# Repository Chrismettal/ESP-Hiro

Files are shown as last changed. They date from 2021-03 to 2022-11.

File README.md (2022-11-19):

# ESP-Hiro 広 <!-- omit in toc -->

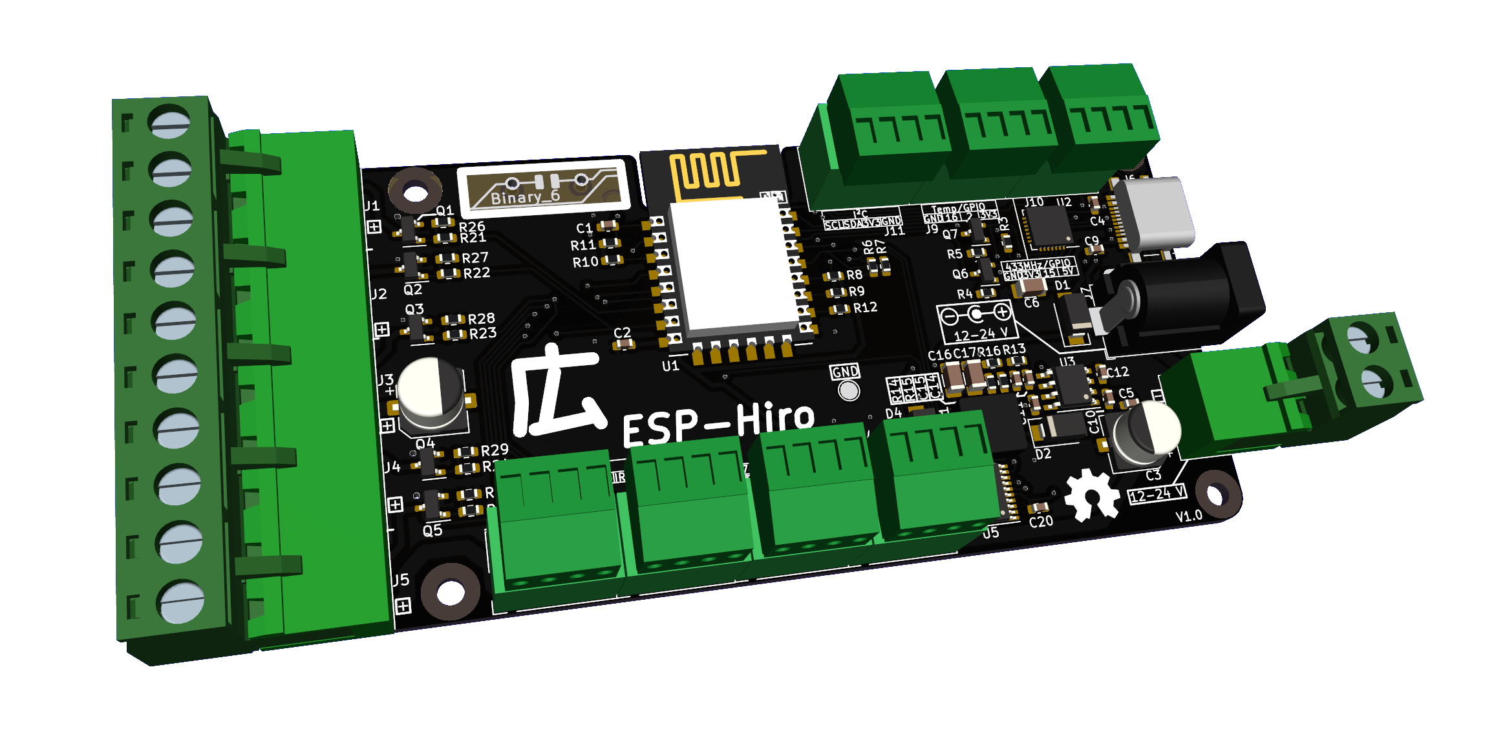
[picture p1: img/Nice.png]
Board


## Interested in buying?

You can find the mostly assembled kit as well as 3D printed parts over at my tindie store!



**If you like my work please consider [supporting my caffeine addiction](https://gitlab.com/Chrismettal#donations)!**

# Contents

- [Contents](#contents)
- [What is this?](#what-is-this)
- [Pin tables](#pin-tables)
  - [Devices](#devices)
- [Defined I/O](#defined-io)
  - [MOSFETs](#mosfets)
  - [IR](#ir)
  - [Relays](#relays)
  - [I²C](#ic)
    - [PCF8574](#pcf8574)
    - [Temperature Sensors](#temperature-sensors)
    - [433MHz](#433mhz)
    - [ADC](#adc)
    - [Other](#other)
- [Software](#software)
  - [Tasmota](#tasmota)
  - [Other](#other-1)
- [Build / aquire / use](#build--aquire--use)
  - [Buying](#buying)
  - [Building my own](#building-my-own)
  - [3D printing](#3d-printing)
  - [Mechanical](#mechanical)
  - [Power supply](#power-supply)
  - [Jumpers](#jumpers)
    - [V-USB -\> +5V](#v-usb---5v)
    - [PCF8574](#pcf8574-1)
    - [IR resistor](#ir-resistor)
    - [Deep sleep](#deep-sleep)
  - [Uploading the Firmware](#uploading-the-firmware)
  - [Templates](#templates)
- [Tools used](#tools-used)
- [Other boards](#other-boards)
  - [CP2102 USB - serial converter](#cp2102-usb---serial-converter)
  - [24 - 5 V step down converter](#24---5-v-step-down-converter)
- [Changelog](#changelog)

# What is this?

This is a Tasmota compatible dimmer/actuator/sensor and general purpose smart home interface board to either make various devices smart or create new ones. Typical uses include RGBW dimming, single/multi room heating control, even automating plants!

ESP-Hiro has multiple interfaces directly on board which allow you to connect almost anything you would want to have automated. Some parts like a DHT22 or an IR blaster are basically pre-wired on board, all of the ESP8266's usable GPIO are broken out to plugs/sockets, and since the board was (and still is) pretty empty I've thrown in a PCF8574 port expander in case you might think of a usecase with more pins than the ESP has. 

My house is already "smarted-up" with an old version of this, but as I am replacing the old version with this one I will update this repo with the templates of my nodes and pictures of the usecases.

# Pin tables

## Devices

This table shows the hardware that is enabled on the PCB right away. Obviously other hardware can be connected using the I/O headers as you please. `PD` pins are pulled down, `PU` are pulled up.

| | `GPIO2` (PU) | GPIO4 (PU) | GPIO5 (PU) |  GPIO12 (PD) | GPIO13 (PD) | GPIO14 (PD) | `GPIO15` (PD) | `GPIO16` (PD) | `ADC` |
| --- | :---: | :---: | :---: | :---: | :---: | :---: | :---: | :---: | :---: |
| Header for I/O | Temp | SDA | SCL | 12 | 13 | 14 | 15 | 16 (HIGH AT BOOT)  |  ADC  |
| I²C | | SDA | SCL | | | | | | |
| Deep Sleep | | | | | | | Disable | RST | |
| ADC | | | | | | | | | X |
| 433Mhz Transmitter | | | | | | | X | | |
| AM2302/DHT22 | X | | | | | | | | |
| DS18x20 | X | | | | | | | | |
| 2.5 A MOSFET PWM | | | | Ch1 | Ch2 | Ch3 | Ch4 | Ch5 (HIGH AT BOOT) | |
| IR Transmitter | | | | | | | | IR | |
| PCF8574 | | SDA | SCL | `INT (jumper)` | | | | | |

| | `GPIO2` | GPIO4 | GPIO5 | GPIO12 | GPIO13 | GPIO14 | `GPIO15` |  `GPIO16` | `ADC` |
| --- | :-----: | :---: | :---: | :---: | :---: | :---: | :---: | :---: | :---: |
| Room Controller |  DHT22  | | | PWM R | PWM G | PWM B | PWM W | PWM Heating | |
| Switching Actuator | Button  | | | Q1 | Q2 | Q3 | Q4 | Q5 | |
| IR AC Controller | DS18S20 | | | Button 1 | Button 2 | | | IR | |
| Automated Plant |  DHT22  | SDA LCD + Light sensor | SCL LCD + Light sensor | FET water pump | FET fertilizer pump | PWM light | SR04 Trigger |  SR04 Echo  | Soil Moisture |
| Info Display | | SDA LCD | SCL LCD | Encoder A | Encoder B | Encoder Button | | | |

# Defined I/O

## MOSFETs

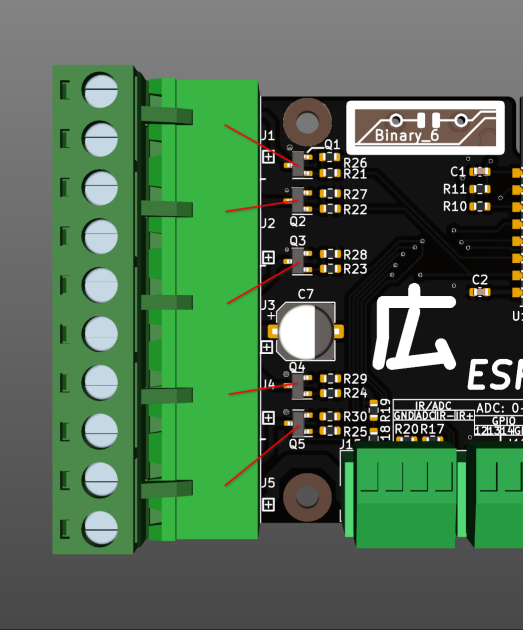
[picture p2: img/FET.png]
FET


On board MOSFETs can be used to switch or PWM dim loads up to 75 W. Uses include RGB-WW-CW LEDs, heating actuators, small motors/pumps etc. The board can supply 5 A overall, every FET individually can provide up to 2.5 A. Q5 WILL be high at boot, so LEDs connected to this FET will blink once during initial powerup of the board!

- Used FET = AO3400A
- Imax per FET = 2.5 A
- Imax over all FETs = 5 A 
- U = 12 - 24 V

## IR

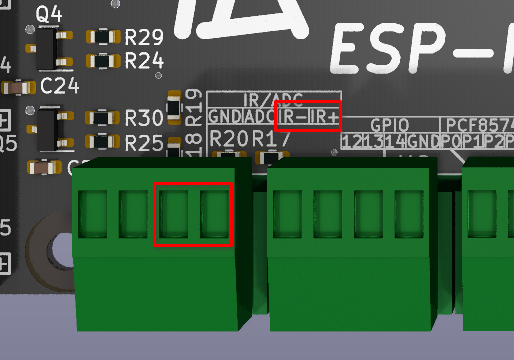
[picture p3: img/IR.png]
IRJack


A header for an IR blaster is present, connected via the MOSFET Q5. It is supplied by 5 V via a jumper configurable current limit resistor of `180 Ohms / 33 Ohms` which works out to around `20 mA / 100 mA` depending on your diodes forward voltage.

`!WATCH OUT!` if you attempt to use an IR LED on J15 and a 24 V device on J5 at the same time you will find that you are connecting the 24 V rail to the 5 V rail through your devices and you will NOT have a fun day! Use ONLY an IR blaster OR a 24 V device at J5!

## Relays

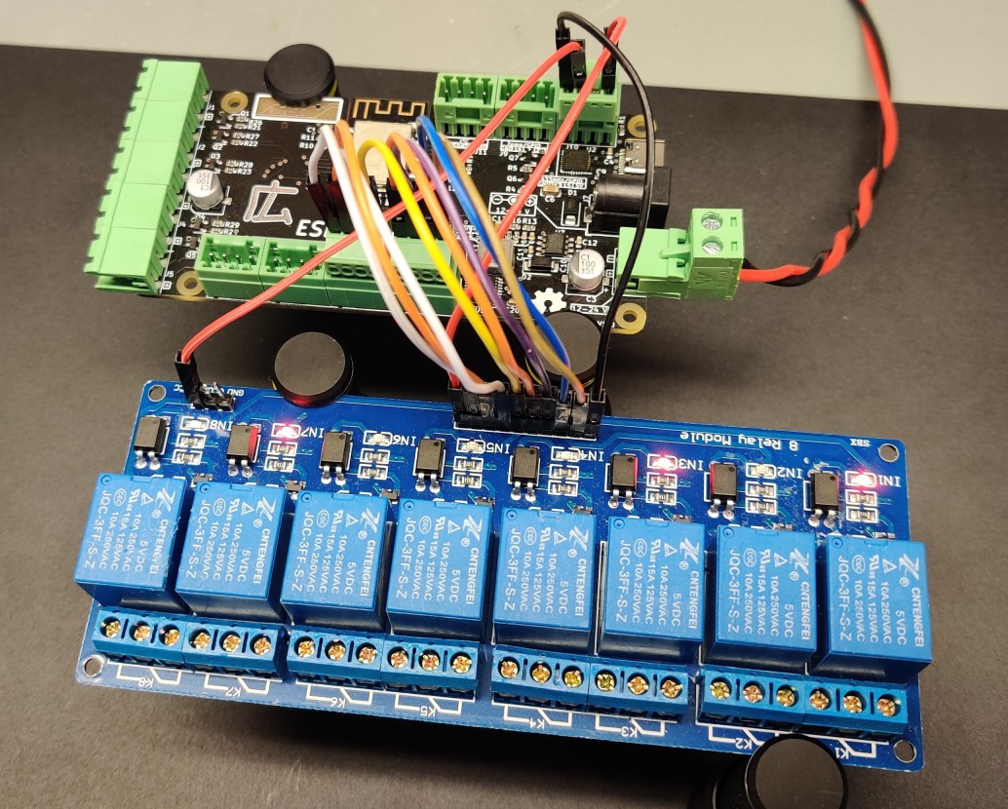
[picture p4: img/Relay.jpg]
RelayBoard


These relay boards can be connected to basically any GPIO from the pin table you want, but you need to disconnect "JD-VCC" jumper and supply 3.3 V to JD so you don't feed 5 V back into the ESP. They can also be connected to the PCF8574 expander header outputs if configured accordingly.

## I²C

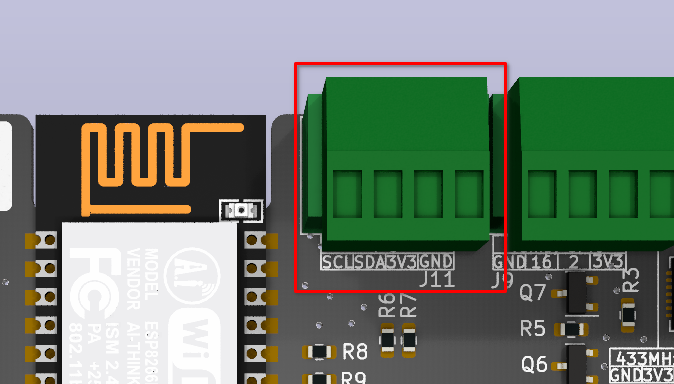
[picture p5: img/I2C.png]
I2C


- `SDA = GPIO4`
- `SCL = GPIO5`

Any I²C devices supported by Tasmota will work, but remember that some devices already include pullup resistors that need to be removed. For example HD44780 LCDs with PCF8574 I²C backpacks will pull up the I²C lines to 5 V, which could damage the ESP and is not needed since I²C is already pulled up to 3.3 V on ESP-Hiro.

For all I²C devices you will have to enable the I²C driver once per command line with `I2Cdriver22 1`

### PCF8574

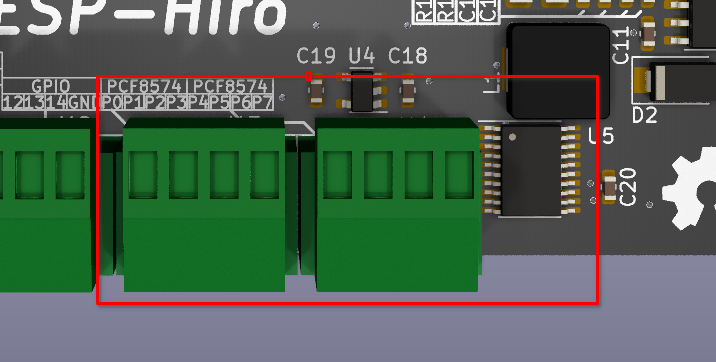
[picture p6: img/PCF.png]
PCF


Tasmota supports Inputs and Outputs over PCF8574 expanders, but to interrupt on input changes GPIO12 needs to be connected to the expander interrupt pin with JP8. Beware that this needs to apply a pullup to GPIO12 with will turn Q1 on! The address of the PCF8574 has to be set with 3 jumpers as well. JP6 enables the PCF at all. 

Setting the following jumpers will enable the PCF including the interrupt pin, and set the PCF address to `0x39` which will be found by Tasmota:

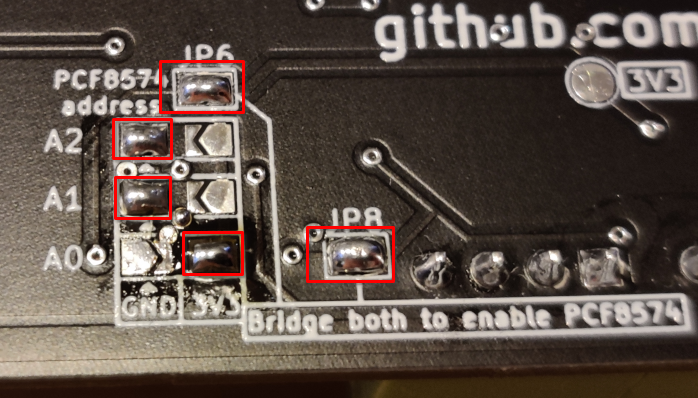
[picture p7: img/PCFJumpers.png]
PCFJumper


### Temperature Sensors

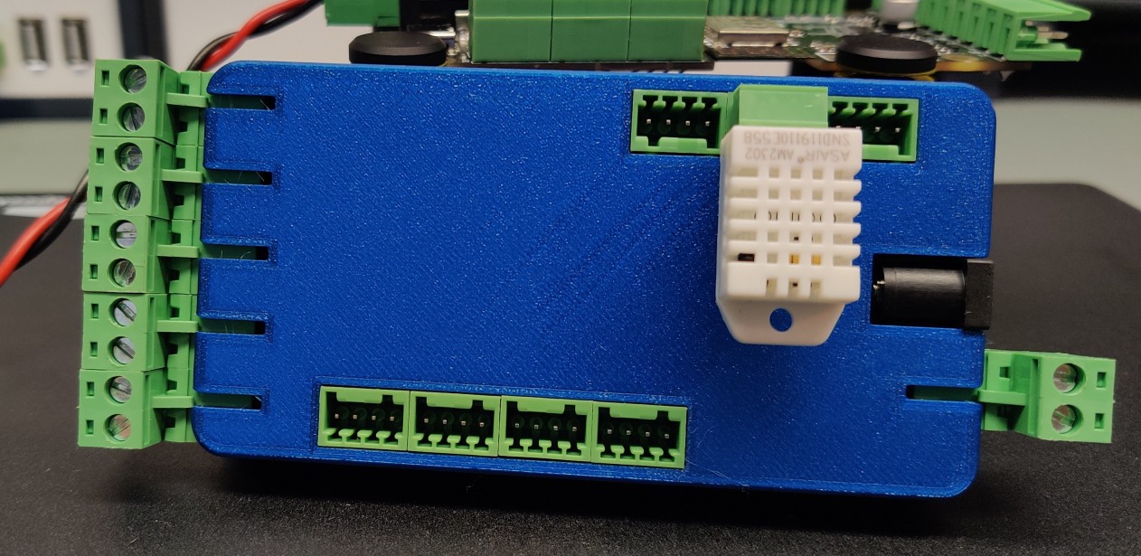
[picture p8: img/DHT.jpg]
Temp


While you can use any temperature sensor supported by Tasmota, the two predefined variants are DHT22 and DS18B20 type sensors. Both are defined to go on `J9` and use `GPIO02`.

### 433MHz

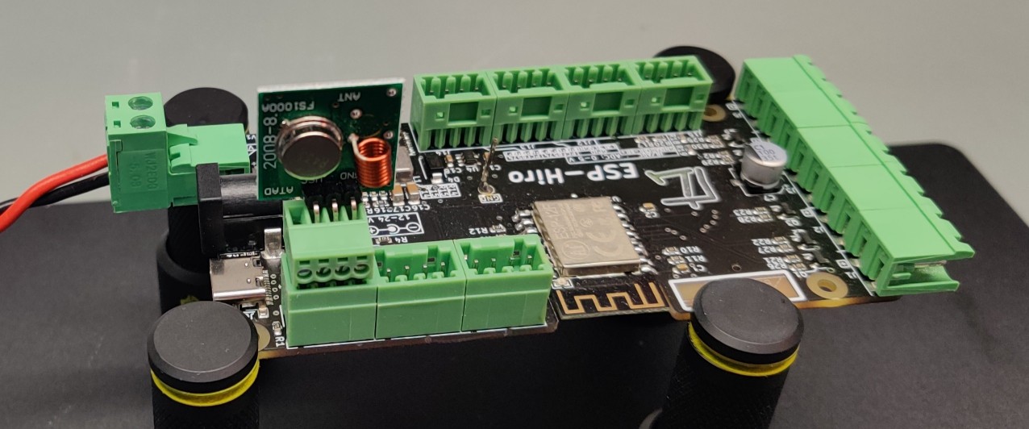
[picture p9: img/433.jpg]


A 433MHz antenna can be plugged straight onto J10, using pin 2-4, which will use GPIO15 for the RC-Switch library.

### ADC

The ADC has a voltage divider in place to measure 0 - 5 V over the 0 - 1023 ADC range

### Other

Tasmota does way more than I anticipated so you can use everything that Tasmota provides, even if not specifically defined here. This just happens to be the stuff I regularly use.

# Software

## Tasmota

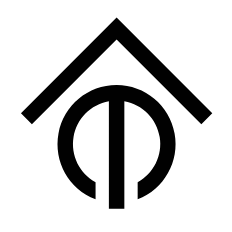
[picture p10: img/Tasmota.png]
Tasmota


Under `/Tasmota/tasmota-ESP-Hiro/` you will find a precompiled `firmware.bin` built for use with ESP-Hiro, as well as a user_config_override.h file so that you can edit your build to your preferences or usecase.
Using the override file requires you to clone the Tasmota repo and placing the override file inside the `/tasmota/` folder there. 

## Other

Obviously as this is basically another ESP8266 devboard you can code your own software in any language you want. The original design of ESP-Hiro was programmed with Arduino but that made it very "hardcoded to my own home" and not flexible enough for publishing. Tasmota is what sparked the idea of a publishable refresh so just use that!

# Build / aquire / use

## Buying

You can find the mostly assembled kit as well as 3D printed parts over at my tindie store!



## Building my own

As this project is fully open sourced you can obviously make your own boards. The whole board is made to be manufactured by JLCPCB and uses their LCSC parts libraries in the BOM. Using the manufacturing files inside the `KiCAD` folder you can have them build the populated PCB for you, but obviously you can just do them by hand if you want! Obviously SMD soldering skills will be required especially for the USB-C terminal, and parts like the CP2102 are best done with a hot air gun, but these two parts aren't even required if you don't plan to upload code via USB.

Right now there is no build guide for soldering one yourself since this was an exercise in design for manufacturing, specifically to get a fully working module delivered from the PCBA house. 

## 3D printing

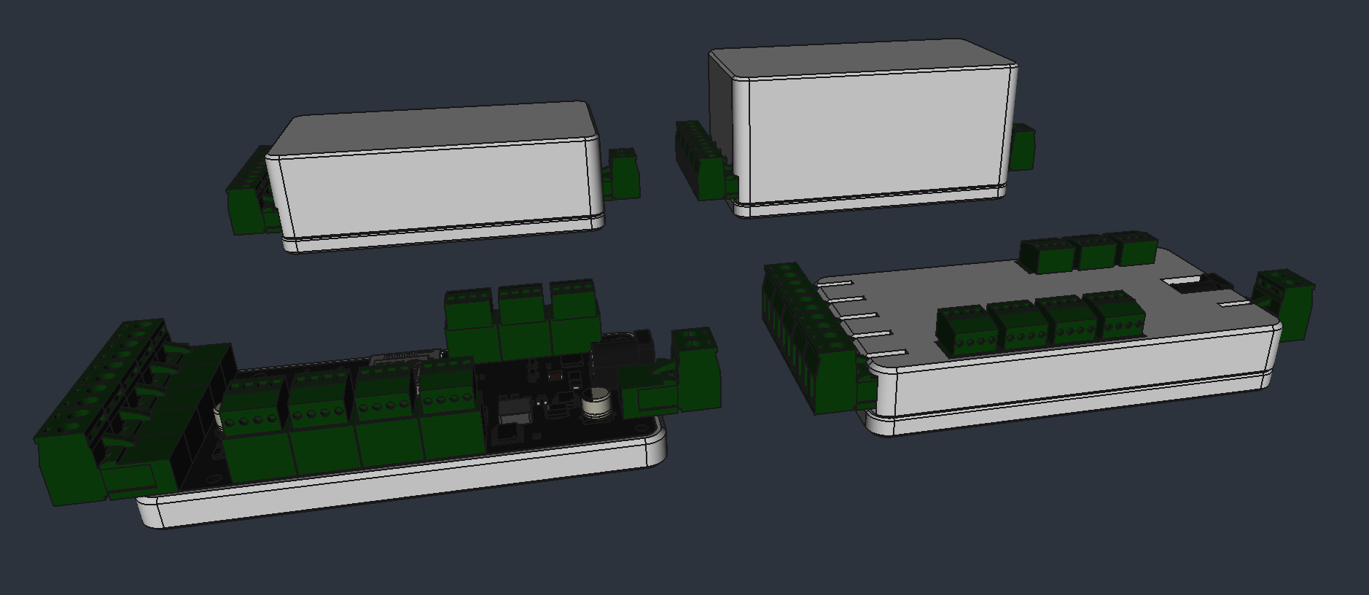
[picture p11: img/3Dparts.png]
3DParts


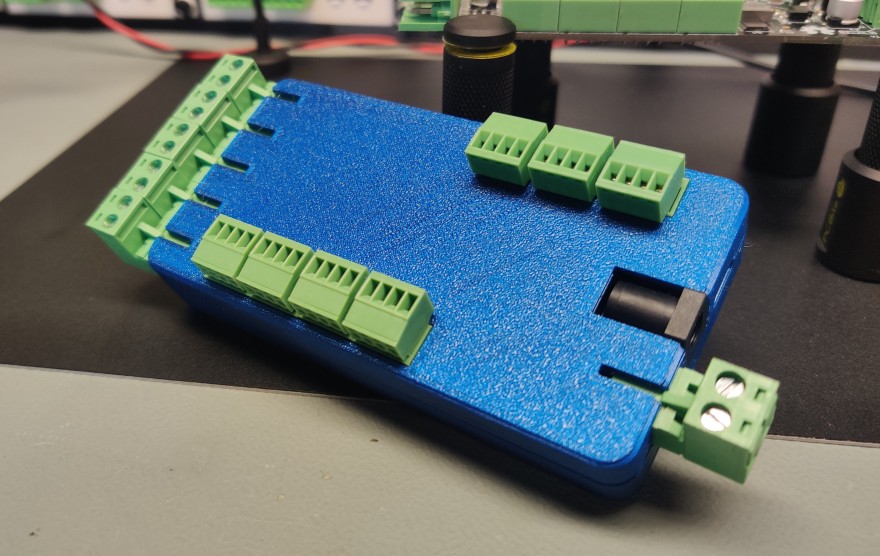
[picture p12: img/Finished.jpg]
Finished


The FreeCAD project file (done in 0.20 dev versions) contains parametric design files for 4 different cases. There is one "Shoe" that only covers the bottom of the PCB, one "Slim" case exposing all connectors, and two "Thicc" cases, only exposing the side connectors. For these variants, printable stl files are exported in the FreeCAD/stl folder.

All cuts and breakthroughs are done in the last steps of each body, so should choose to only populate one of the PWM jacks you can delete the "pocket" operations for the other PWM jacks. The same applies to the screwholes in the bottom as well as most other jacks.

You can also find the project on [PrusaPrinters](https://www.prusaprinters.org/prints/66847-esp-hiro-cases-smart-home-devboard-tasmota-compati)!

## Mechanical

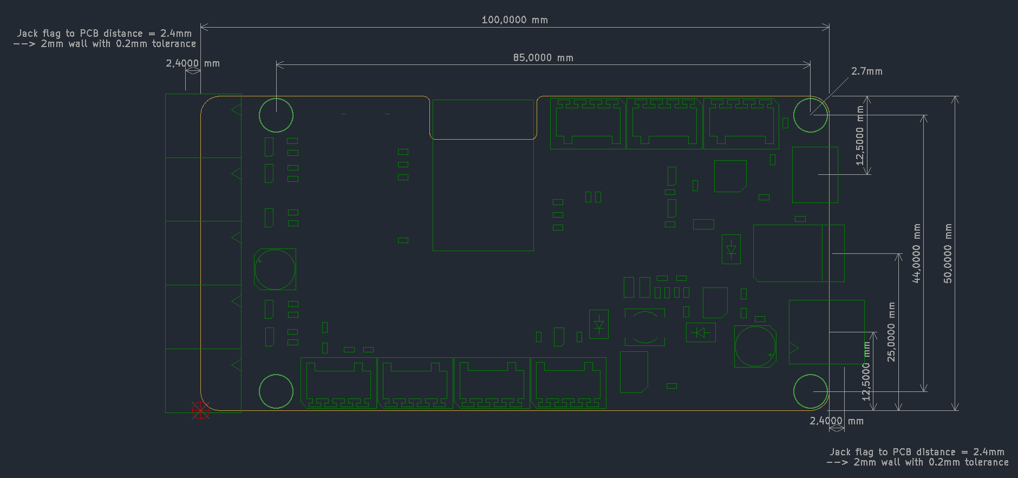
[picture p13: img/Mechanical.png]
Mechanical


This is the mechanical drawing. Under the KiCAD folder /renders you will also find the STEP file for the whole board which makes it easier to design your case around it.
The screwholes are 2.75mm for 2.5mm screws to pass.
Walls around board should be 2mm thick, with 0.2mm space between the board and the wall for the 5.08mm plugs to fit nicely.

## Power supply

The PCB can be easily supplied via 5 V or 12-24 V depending on your usecase. Only the MOSFETs are exclusively supplied through the 12-24 V DC input, everything else will work on 5 V as well.

To supply the unit via 5 V you can use either the USB Jack or via J10:

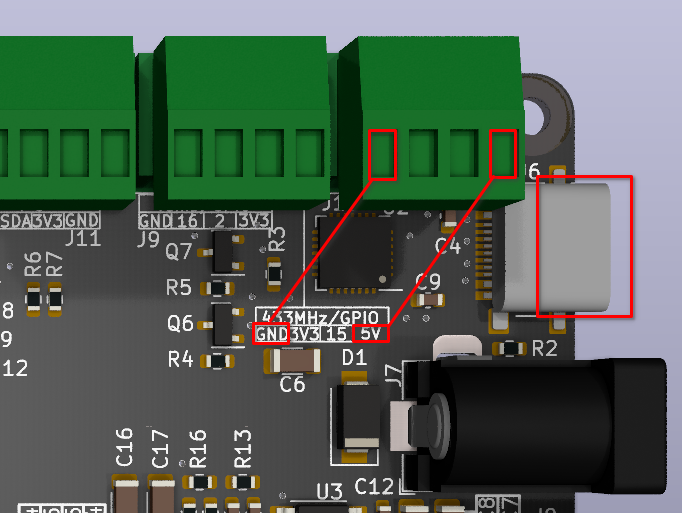
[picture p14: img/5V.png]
5V


12-24 V are supplied via either the barrel jack J7 or the screw-plug terminal J8:

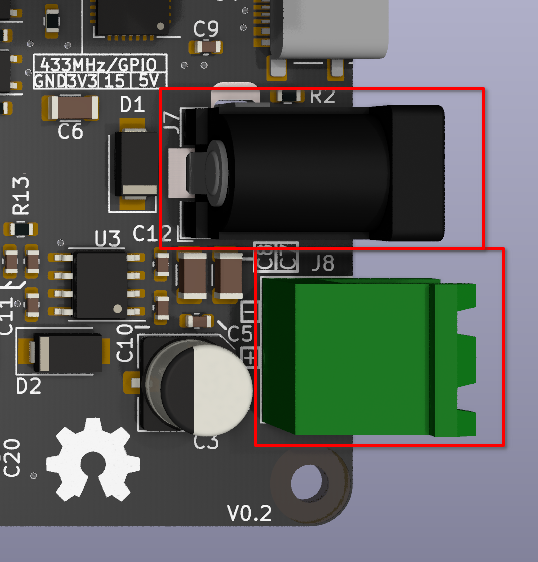
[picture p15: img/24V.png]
24V


The designed current for this board is a maximum of 5 A through the 24 V terminal, which provides you up to 120 W of dimming power, which is plenty for most at-home LED dimming uses. At least for me. 

Using the 3V3 header also works to supply the ESP, but the IR LED for example won't work anymore as it is supplied by 5 V.

## Jumpers

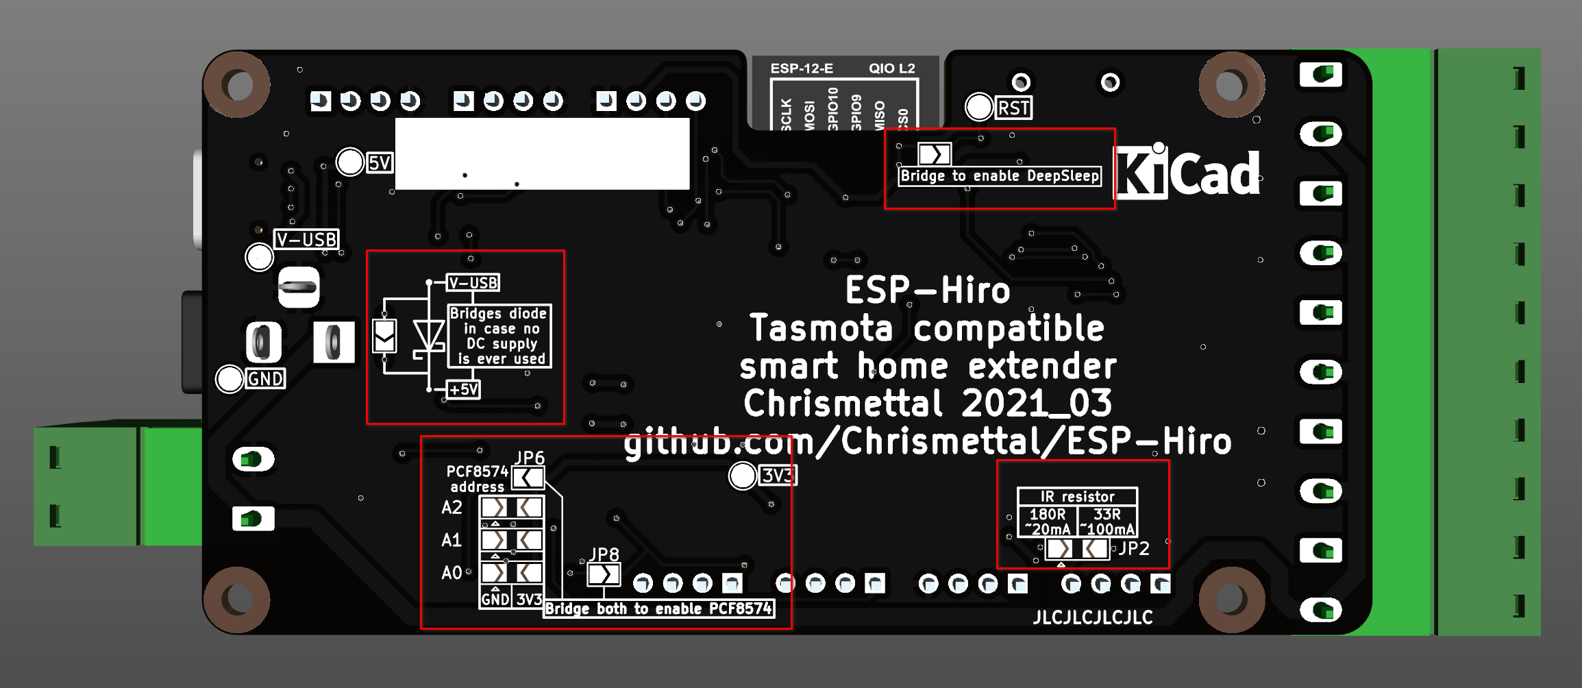
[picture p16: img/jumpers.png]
Jumpers


All jumpers are on the bottom side of the board. 

- To use the PCF8574 you will have to set an I²C address on the three jumpers labled A0 - A2 as well as bridge both marked jumpers to power on the PCF (JP6) and connecting the interrupt line (JP8, not strictly required if only outputs are used).
- To use an IR blaster configure the LED current through one of the two jumpers at JP2 to around 100mA / 20mA.
- To use DeepSleep you will need to bridge the labeled jumper to connect GPIO16 to RST

### V-USB -> +5V

This jumper can be used to short out the protection diode between USB and the 5 V rail if you are only using the USB to supply the board. Might save some power for very low power applications and prevents some voltage drop for the IR blaster for example.

### PCF8574

JP6 and has to be shorted to enable the PCF at all, JP8 will connect the PCF interrupt line to GPIO12 and you will have to set a free address with A0 - A2. I use `A0 HIGH ; A1 LOW ; A2 LOW` in my build

### IR resistor

With JP2 you can choose the current limiting resistor before your IR blaster LED. Shorting the left side yields around 20mA LED current, while the right side yields around 100mA, depending on your diode.

### Deep sleep

Deep sleep will only work if this jumper is bridged. It connects `GPIO16` to the reset line.

## Uploading the Firmware

You best check out the official Tasmota guides for this, as it won't differ from any other ESP8266 board. There is a CP2102 serial converter behind the USB jack so for most systems the board will be plug-and-play to upload via USB. The serial design generally mimics the NodeMCU way of things. TXD and RXD pins are NOT broken out to headers so if you want to upload code without USB you would have to solder directly to the generous pins of the ESP directly!

## Templates

Use this preconfigured base template that sets all broken out pins to "User" and allows you to create your own configuration out of the Module setting:

`{"NAME":"ESP-Hiro_v1.0","GPIO":[0,0,1,0,1,1,0,0,1,1,1,1,1,1],"FLAG":0,"BASE":18}`

A room controller dimmer template including all 5 PWM outputs, I²C enabled, a DHT22 temperature sensor and an ADC input would look like this:

`{"NAME":"ESP-Hiro_v1.0_RoomDimmer","GPIO":[0,0,1216,0,640,608,0,0,416,417,418,419,420,4704],"FLAG":0,"BASE":18}`

# Tools used

The schematic, PCB and screenshot renders were done in __[KiCAD](https://kicad.org/)__ 5.99 nightly builds. The whole KiCAD project, all design files and manufacturing outputs are found under the `PCB` folder, including the schematic etc.

All the 3d printable files are done in __[FreeCAD](https://www.freecadweb.org/)__ 0.20 dev versions. Find all 3d printable files in the `3DPrinting` folder as well as on __[Prusaprinters.org](https://www.prusaprinters.org/social/13425-chrismettal/prints)__. 

Models are printed on __[Prusa](https://www.prusa3d.com/)__ MK3s printers and sliced with Prusaslicer. 

# Other boards

For some reason, I have left two boards, designed during prototyping in this repo as well. The two boards are basically snippets from the actual board, to test the serial connection as well as the power supply early.

The two boards are:

## CP2102 USB - serial converter

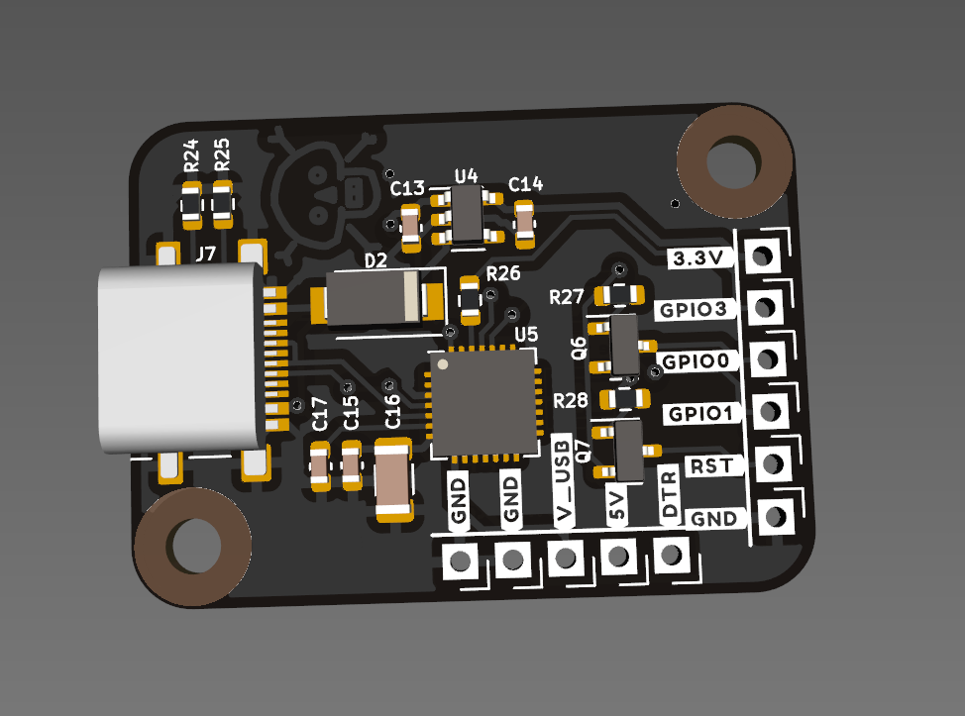
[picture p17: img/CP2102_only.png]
CP2102


The CP2102 only, as a fully functional USB-Serial converter to interface with your ESP or whatever you want

## 24 - 5 V step down converter

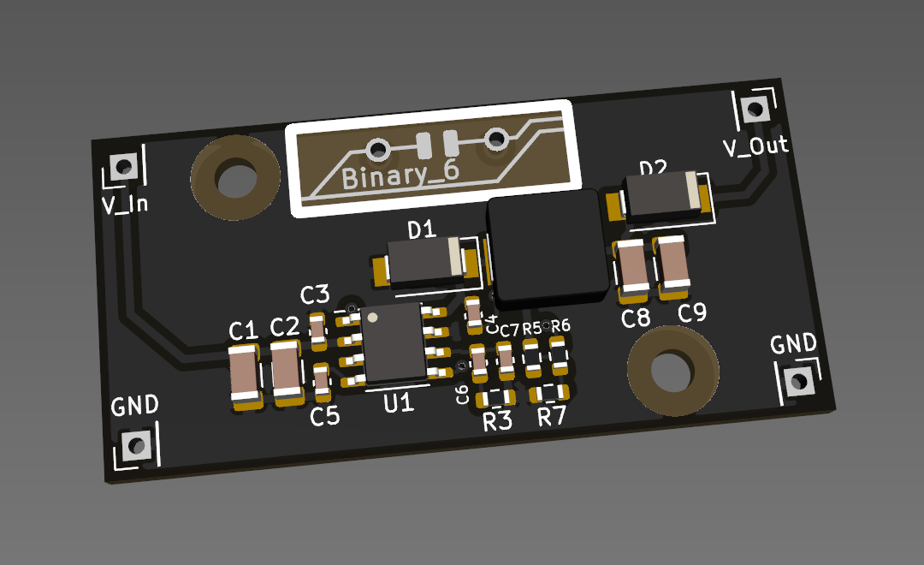
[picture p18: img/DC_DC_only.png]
DCDC


Just the 24 V to 5 V step-down converter. Fixed to output about 5 V after the output diode.

# Changelog

- V0.2    - Initial prototype
- V1.0    - Initial release - fixed PCF8574 pinout and updated some silkscreen documentation - fully tested working
- V1.0.1  - Minor silkscreen documentation updates - current production run available at Tindie
- V1.0.2  - Minor silkscreen update, change GitHub to GitLab in info link, not ordered and no gerbers generated yet

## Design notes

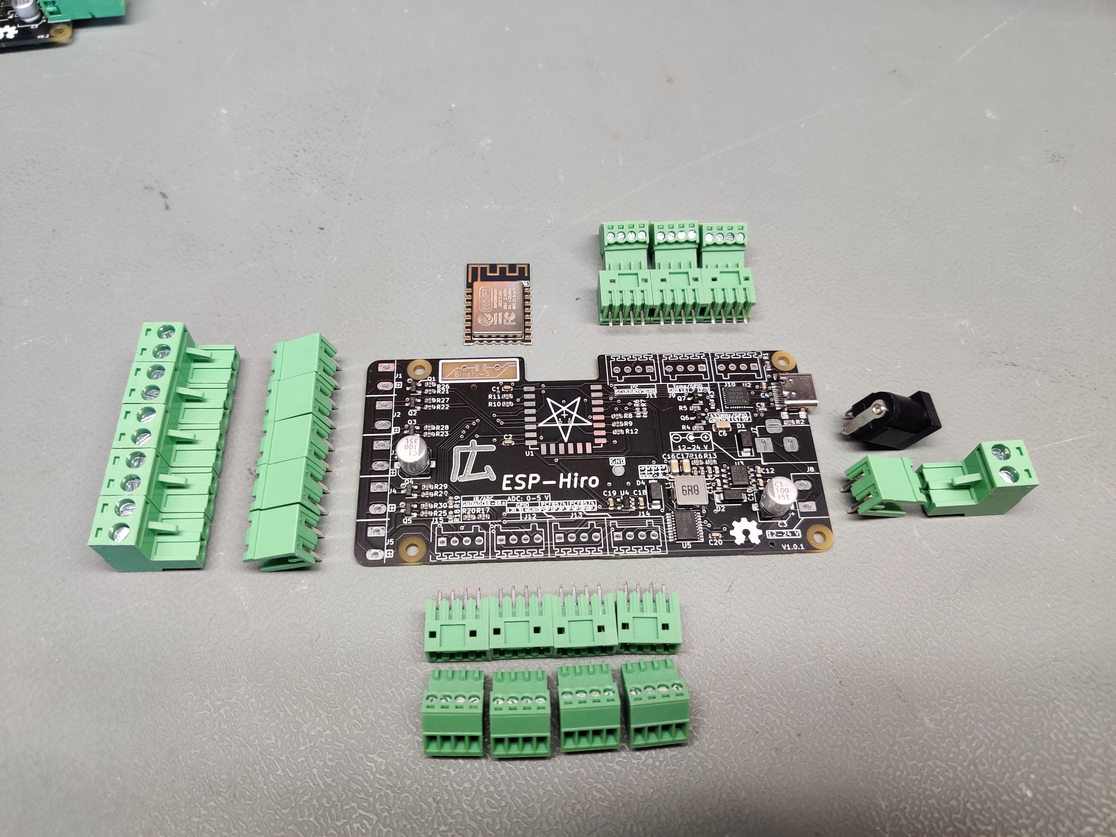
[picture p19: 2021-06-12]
img/Contents.jpg

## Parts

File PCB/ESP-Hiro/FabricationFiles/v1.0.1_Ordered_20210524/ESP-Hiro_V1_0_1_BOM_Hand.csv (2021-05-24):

Comment | Designator | Footprint | LCSC
CiKe4pinPlug | J9_1,J10_1,J11_1,J12_1,J13_1,J14_1,J15_1 |  | C577528
CiKe2PinPlug | J1_1,J2_1,J3_1,J4_1,J5_1,J8_1 |  | C71370
CiKe4pinSock | J9,J10,J11,J12,J13,J14,J15 | MeineBib:CixiKefa_KF2EDGV_2.54_4xSocket | C577587
CiKe2PinSock | J1,J2,J3,J4,J5,J8 | MeineBib:Cixi_Kefa_Elec_KF2EDGR-5.08-2P | C8383
Barrel_Jack_Switch | J7 | Connector_BarrelJack:BarrelJack_Horizontal | C381116
ESP-12E | U1 | ESP8266:ESP-12E_SMD | C82891
LED | D3 |  | C5119

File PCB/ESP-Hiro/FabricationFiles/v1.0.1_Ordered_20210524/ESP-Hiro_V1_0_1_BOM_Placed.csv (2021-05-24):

Comment | Designator | Footprint | LCSC
100nF | C1,C2,C4,C5,C9,C20 | Capacitor_SMD:C_0603_1608Metric | C14663
10nF | C10,C11,C12 | Capacitor_SMD:C_0603_1608Metric | C57112
4.7nF | C14 | Capacitor_SMD:C_0603_1608Metric | C53987
33pF | C15 | Capacitor_SMD:C_0603_1608Metric | C1663
47uF | C16,C17 | Capacitor_SMD:C_1206_3216Metric | C96123
1uF | C18,C19 | Capacitor_SMD:C_0603_1608Metric | C15849
100uF | C3,C7 | Capacitor_SMD:CP_Elec_6.3x5.8 | C249982
10uF | C6 | Capacitor_SMD:C_1206_3216Metric | C13585
SS14 | D1,D2,D4 | Diode_SMD:D_SMA | C2480
XUNPU TYPEC-304S-ACP16 | J6 | MeineBib:USB_C_Receptacle_XUNPU_TYPEC-304S-ACP16 | C720630
6.8uH | L1 | MeineBib:Sunltech_SLO0630H | C207841
AO3400A | Q1,Q2,Q3,Q4,Q5 | Package_TO_SOT_SMD:SOT-23 | C693097
S8050_correctpins | Q6,Q7 | Package_TO_SOT_SMD:SOT-23 | C2150
5.1K | R1,R2 | Resistor_SMD:R_0603_1608Metric | C23186
47K | R13 | Resistor_SMD:R_0603_1608Metric | C25819
10k | R14 | Resistor_SMD:R_0603_1608Metric | C25804
1.5k | R15 | Resistor_SMD:R_0603_1608Metric | C22843
220R | R16 | Resistor_SMD:R_0603_1608Metric | C22962
180R | R17 | Resistor_SMD:R_0603_1608Metric | C22828
3k | R19 | Resistor_SMD:R_0603_1608Metric | C4211
33R | R20 | Resistor_SMD:R_0603_1608Metric | C23140
100R | R21,R22,R23,R24,R25 | Resistor_SMD:R_0603_1608Metric | C22775
470R | R3 | Resistor_SMD:R_0603_1608Metric | C23179
12k | R4,R5,R6,R7,R8,R9,R10,R11,R12,R18,R26,R27,R28,R29,R30 | Resistor_SMD:R_0603_1608Metric | C22790
CP2102N-A01-GQFN28 | U2 | Package_DFN_QFN:QFN-28-1EP_5x5mm_P0.5mm_EP3.35x3.35mm | C6568
TPS54331D | U3 | Package_SO:SOIC-8_3.9x4.9mm_P1.27mm | C9865
SE5218ALG-LF | U4 | Package_TO_SOT_SMD:SOT-23-5 | C118233
PCF8574APWR | U5 | Package_SO:TSSOP-20_4.4x6.5mm_P0.65mm | C94361

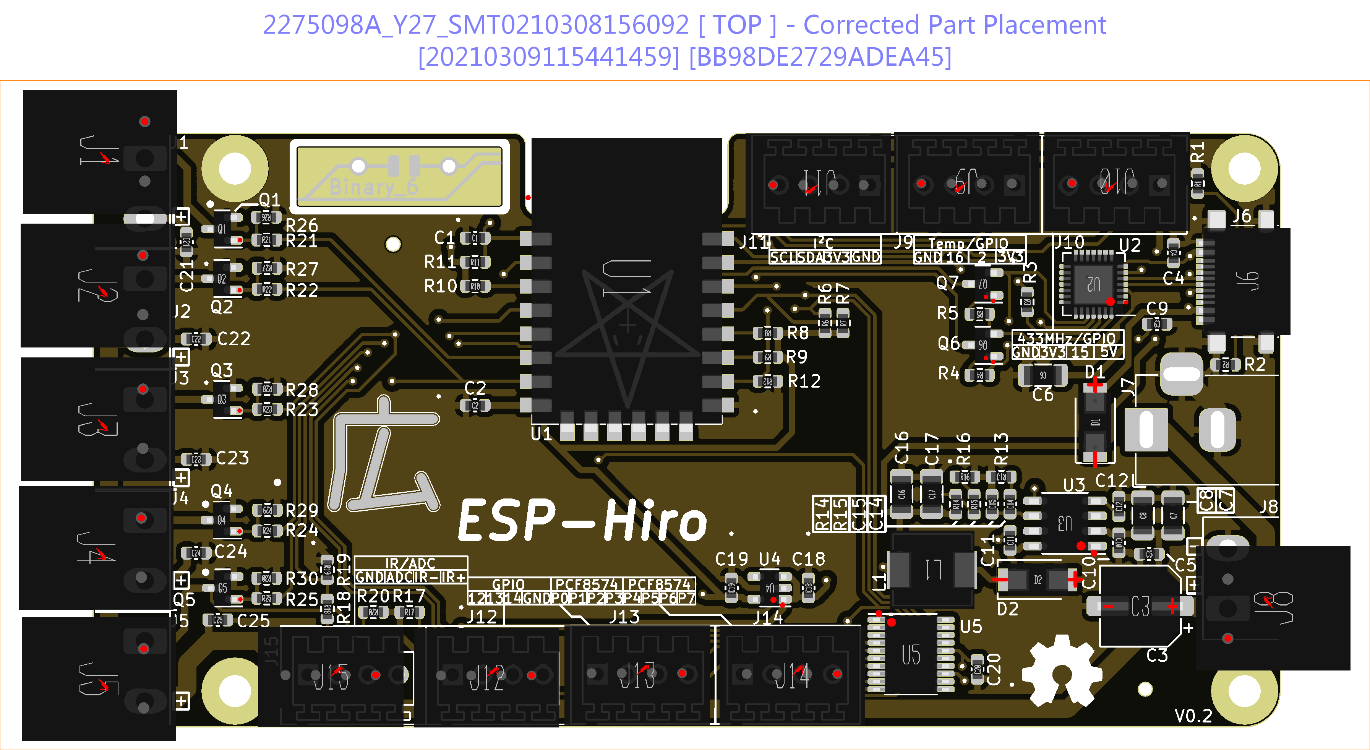
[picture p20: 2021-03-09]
PCB/ESP-Hiro/FabricationFiles/v0.2_Ordered_20210308/Produce_DanZhi.SMT_Corrected_Snapshot.Top.2275098A_Y27.SMT0210308156092.png

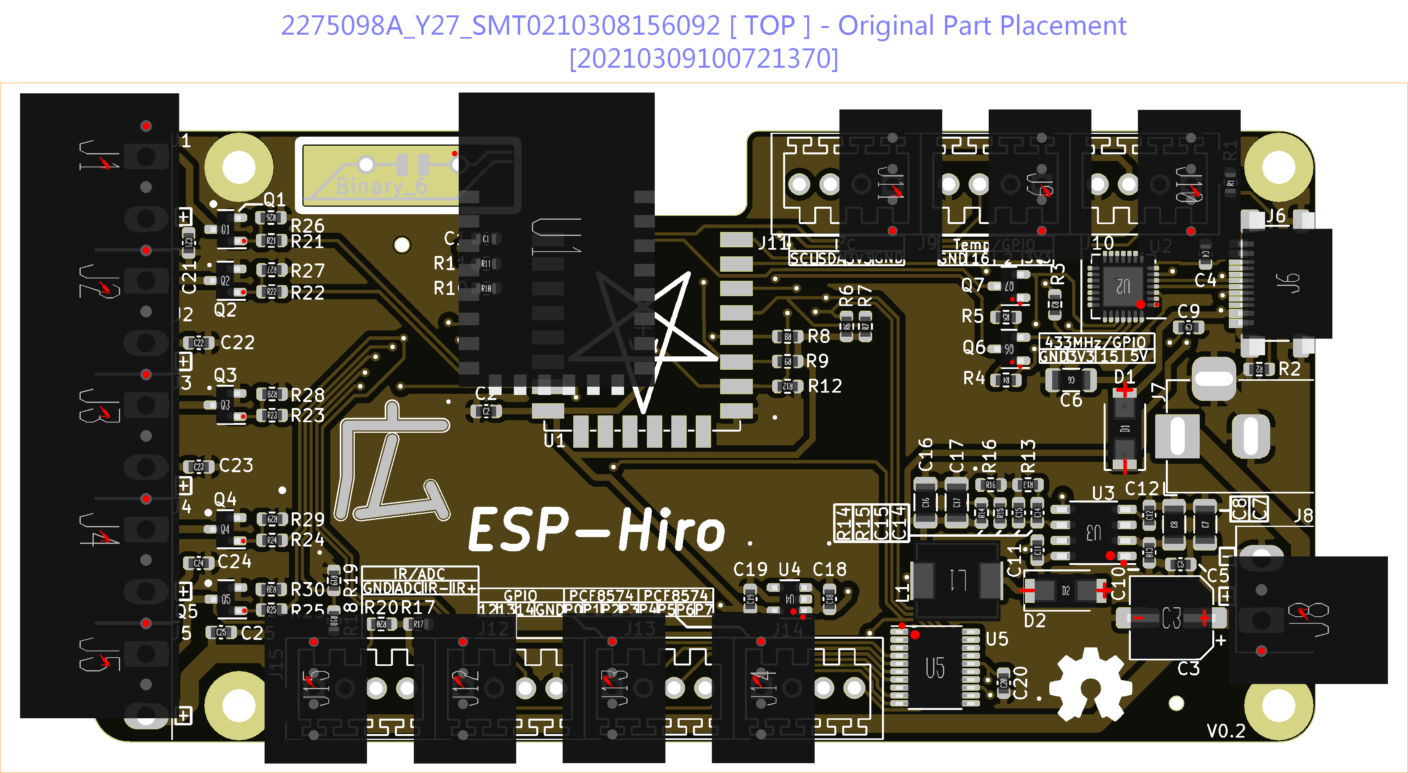
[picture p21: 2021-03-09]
PCB/ESP-Hiro/FabricationFiles/v0.2_Ordered_20210308/Produce_DanZhi.SMT_Original_Snapshot.Top.2275098A_Y27.SMT0210308156092.png

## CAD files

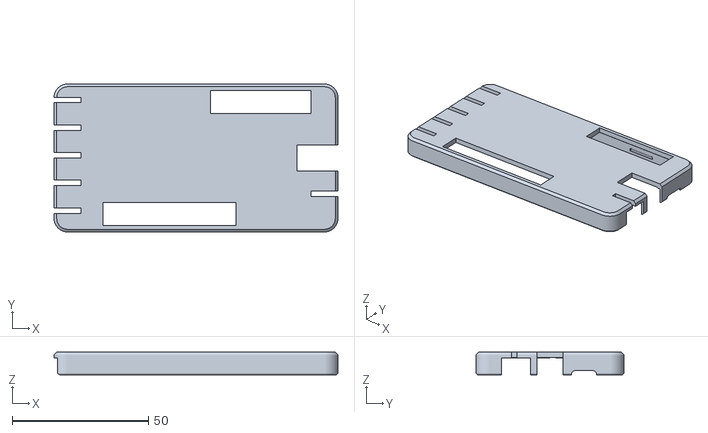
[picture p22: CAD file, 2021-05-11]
3DPrinting/stl/SlimTop.stl
104.4 x 54.4 x 8.30

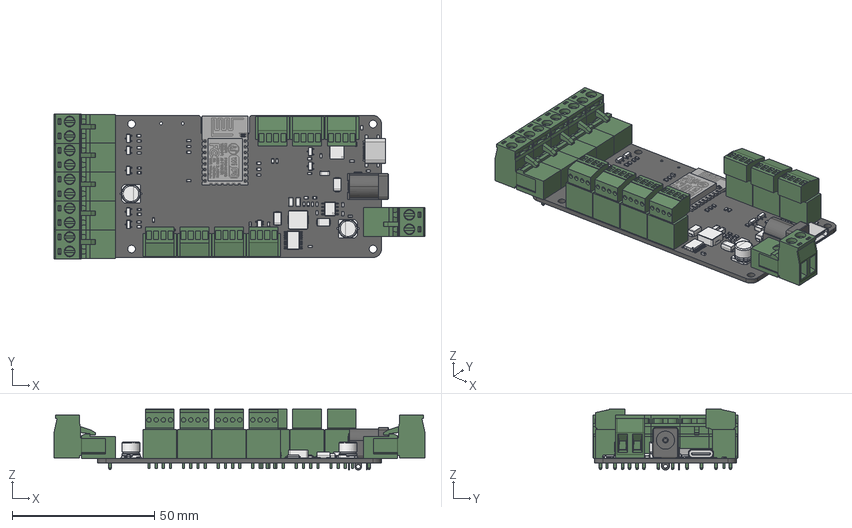
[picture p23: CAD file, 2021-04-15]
FreeCAD/ESP-Hiro.FCStd
130.6 x 50.9 x 21.4 mm

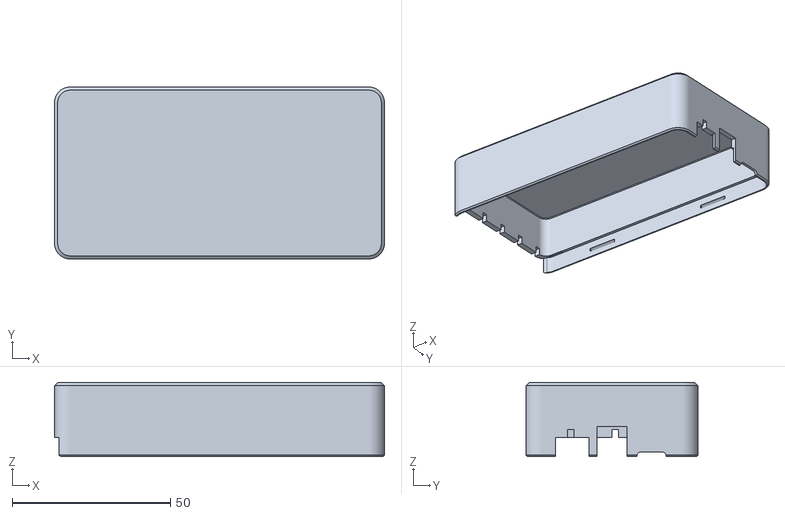
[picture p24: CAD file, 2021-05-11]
3DPrinting/stl/ThiccTop.stl
104.4 x 54.4 x 23.5

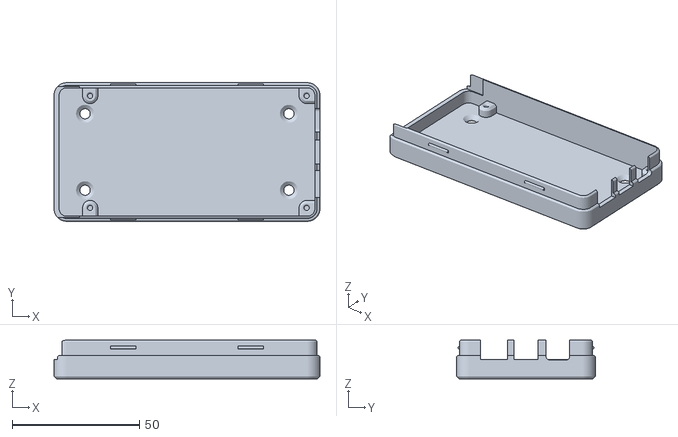
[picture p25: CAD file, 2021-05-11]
3DPrinting/stl/SlimBottom.stl
104.4 x 54.4 x 15.3

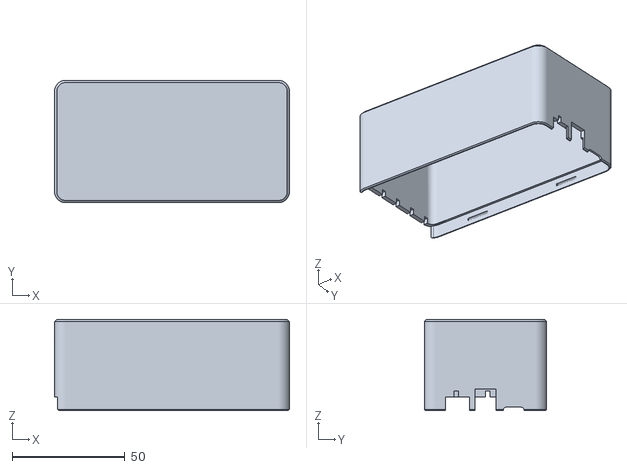
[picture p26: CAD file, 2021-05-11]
3DPrinting/stl/ExtraThiccTop.stl
104.4 x 54.4 x 40.5

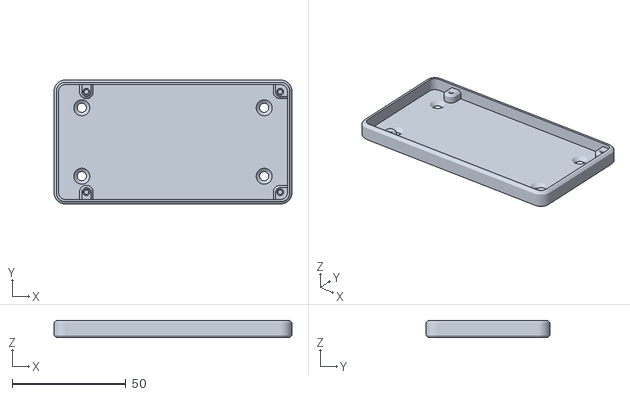
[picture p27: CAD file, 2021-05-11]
3DPrinting/stl/ShoeBottom.stl
104.4 x 54.4 x 7.60

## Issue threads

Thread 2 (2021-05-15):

Feature request: dry-contact inputs, esphome

ptr727, 2021-05-15:
I've long been looking for a general purpose ESP32 board with a variety of IO, very cool project.
For future versions I'd like to see ESP32, ESPHome templates (natieve HomeAssitant support), LiPo charging backup power, 2+ inputs for dry-contact switches used for pule counting (connecting to utility meters), off-board antenna plug (could be part of ESP32 package, but accounted for in case STL file).

Chrismettal, 2021-05-15:
Thank you!

At this time I do not yet see the advantage of ESP32s in this application. What are the usecases for you where a ESP8266 doesn't suffice? An ESP32 version isn't impossible though.

Likewise I have not touched ESPHome at all and instead focused on Tasmota. Gotta take a look at ESPHome and then maybe push a template.

For dry contact switches you can use any GPIO you want and even the PCF ports. I do not know if the PCFs pulse counting is supported in Tasmota at this time, but I am pulse counting over GPIOs. The only thing missing are headers that specifically have GND and GPIO side by side, as I didn't want to waste expensive header contacts on multiple GND points, especially because I often route 3-4 switches with just one GND which could fit to one header then.

Battery backup and an external antenna are actually both part of my next project, which will be a weather station PCB based on the ESP-Hiro design, including Batteries, Solar power, and potentially a bigger antenna to make it into your home Wifi!

Thanks for your feedback!

Closed 2024-04-26.

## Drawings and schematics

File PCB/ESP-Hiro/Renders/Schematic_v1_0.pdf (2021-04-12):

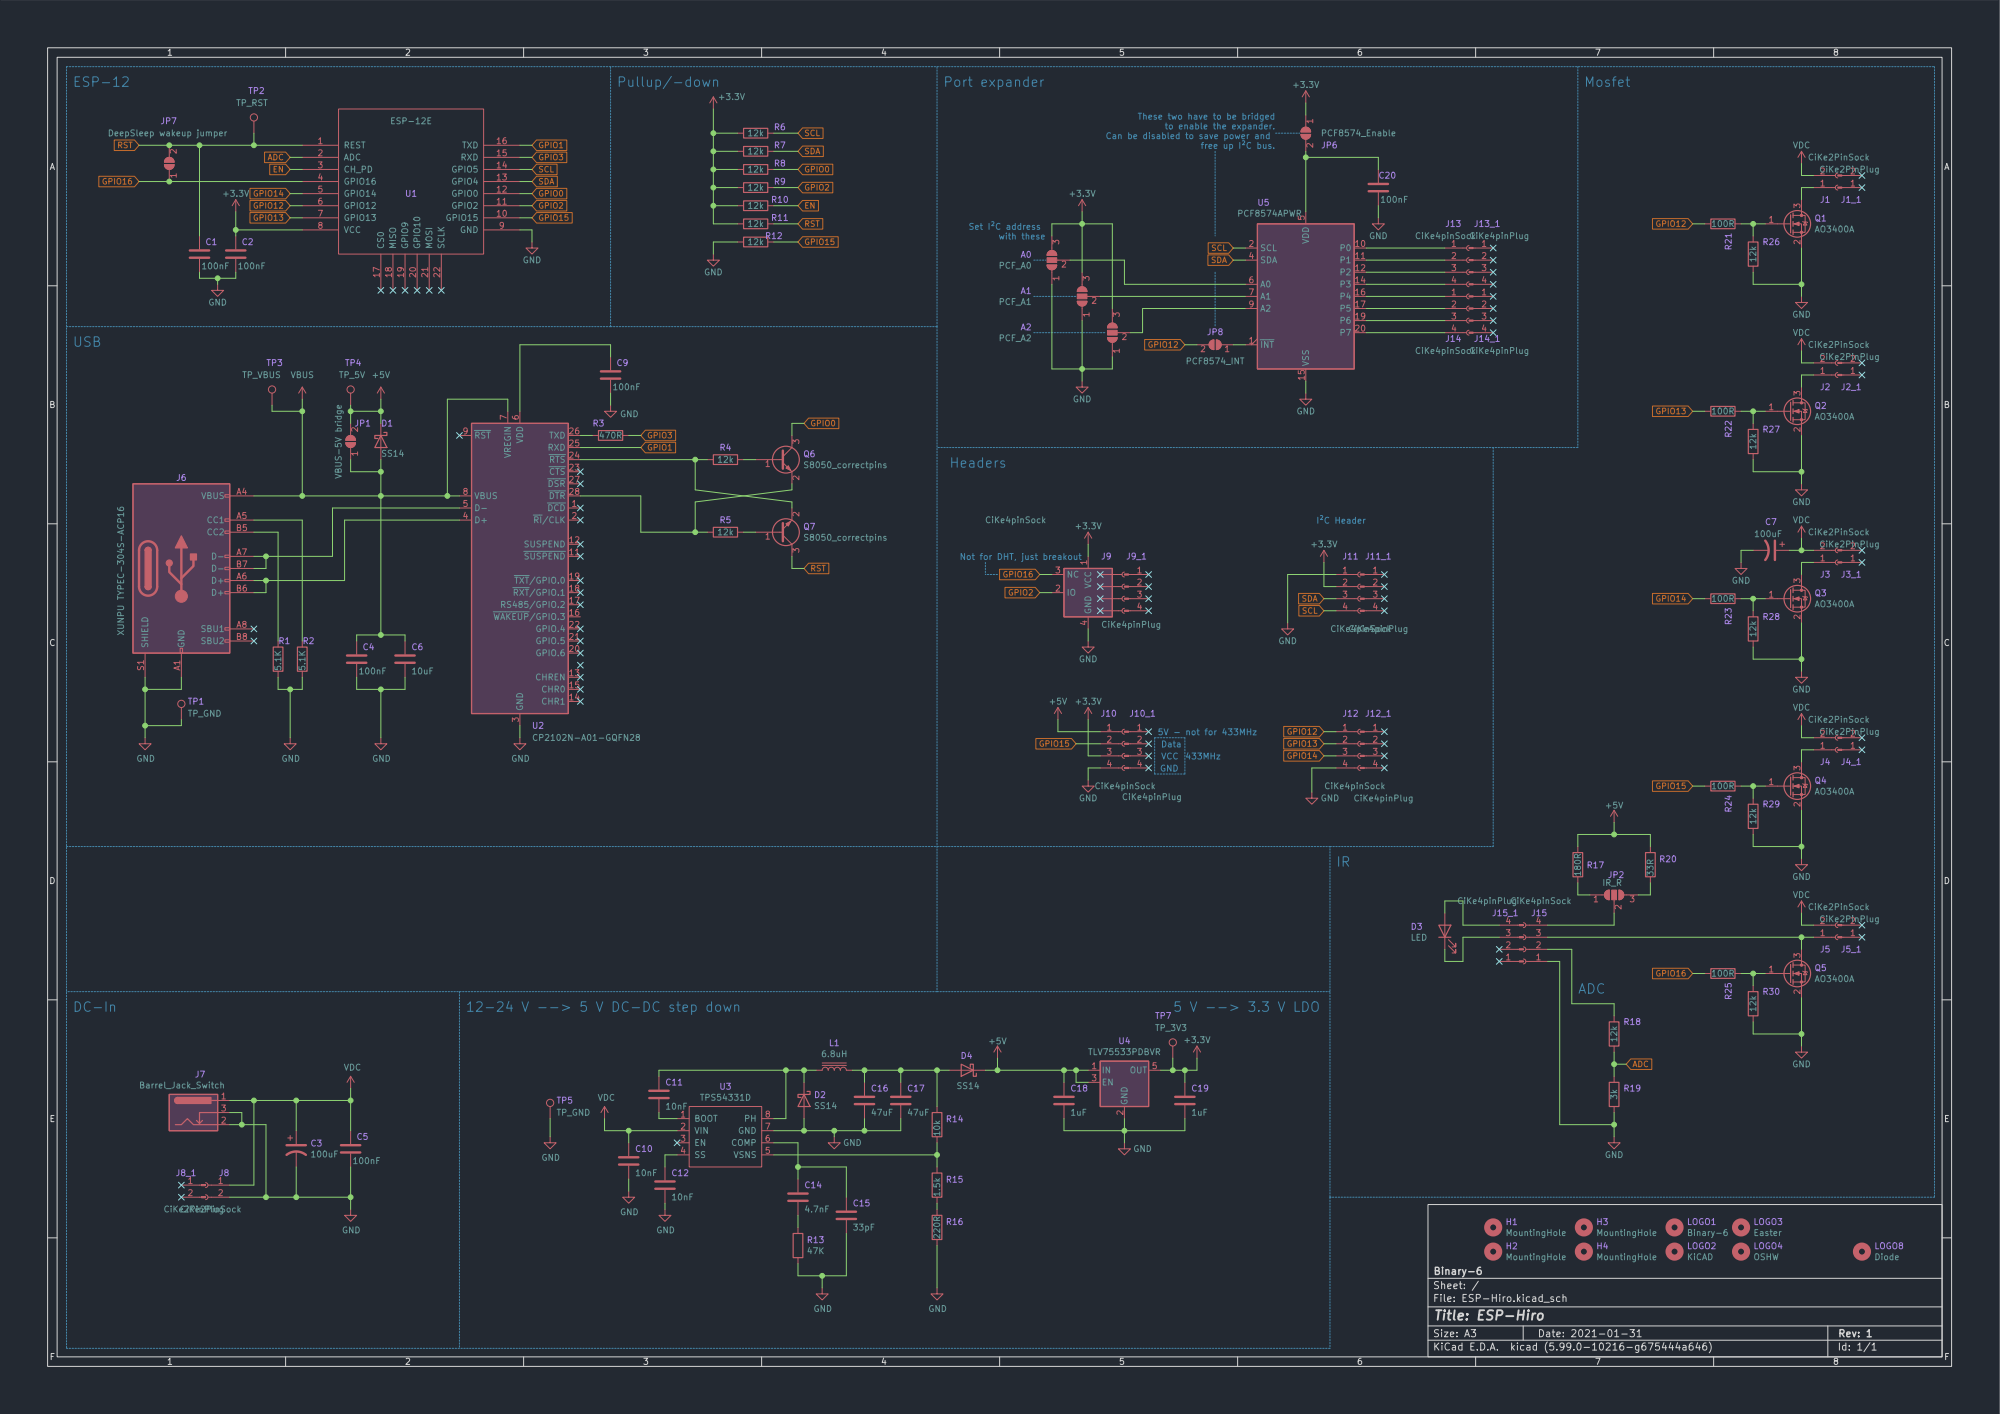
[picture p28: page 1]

These two have to be bridged
to enable the expander.

Can be disabled to save power and

Not for DHT, just breakout

12-24 V --> 5 V DC-DC step down

File: ESP-Hiro.kicad_sch Sheet: / Binary-6

Id: 1/1 Title: ESP-Hiro

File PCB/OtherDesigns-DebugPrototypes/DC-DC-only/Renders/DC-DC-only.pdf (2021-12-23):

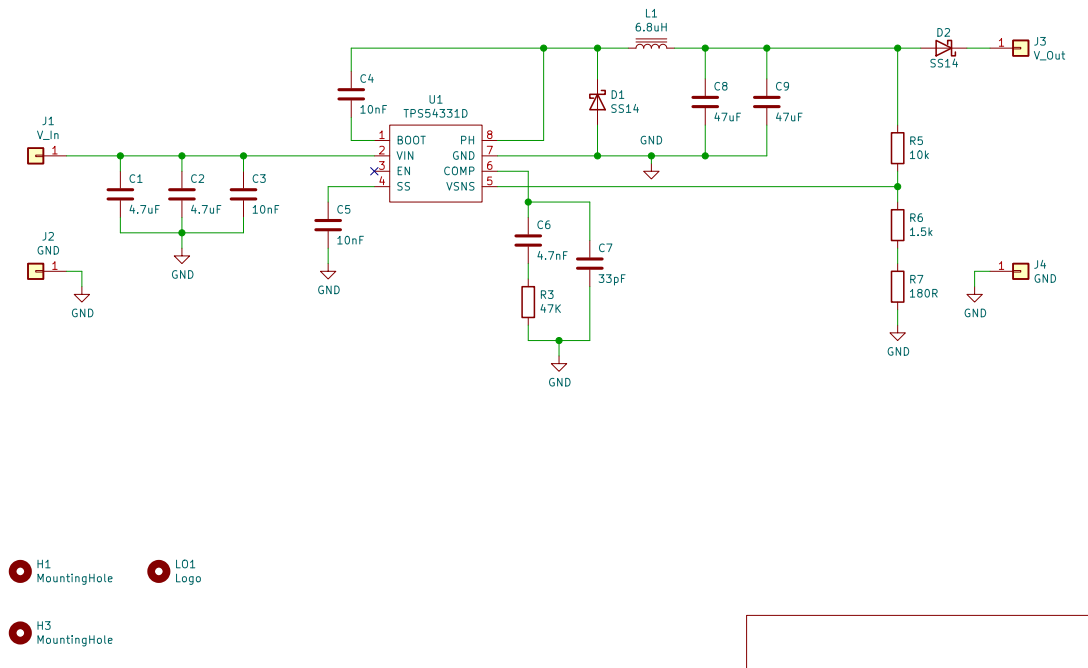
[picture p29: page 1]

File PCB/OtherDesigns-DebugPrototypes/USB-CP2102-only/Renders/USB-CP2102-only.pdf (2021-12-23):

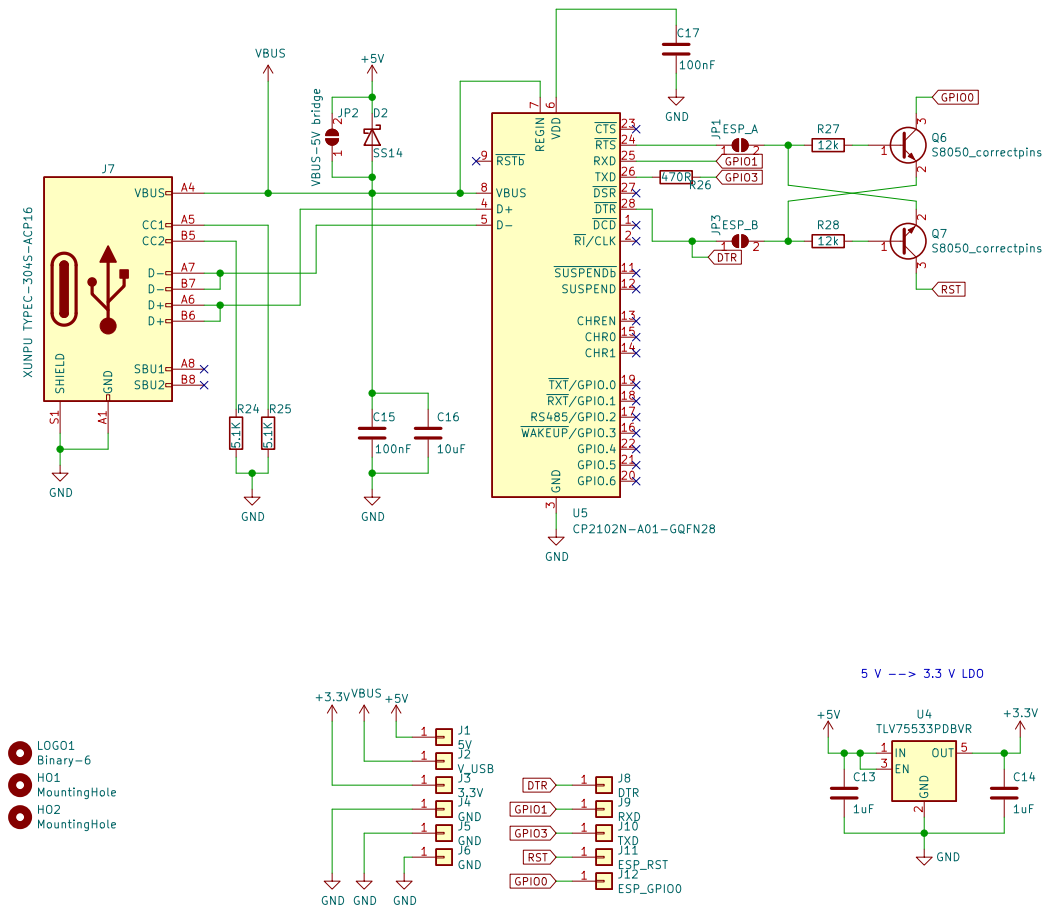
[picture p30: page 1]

Id: 1/1 Title: ESP-Hiro

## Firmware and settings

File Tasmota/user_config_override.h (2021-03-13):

/*
  user_config_override.h - user configuration overrides my_user_config.h for Tasmota

  Copyright (C) 2021  Theo Arends

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
  You should have received a copy of the GNU General Public License
  along with this program.  If not, see <http://www.gnu.org/licenses/>.
*/

//------------------------------------------
//  Override for ESP-Hiro
//------------------------------------------


#ifndef _USER_CONFIG_OVERRIDE_H_
#define _USER_CONFIG_OVERRIDE_H_

// force the compiler to show a warning to confirm that this file is included
#warning **** user_config_override.h: Using Settings for ESP-Hiro ****

/*****************************************************************************************************\
 * USAGE:
 *   To modify the stock configuration without changing the my_user_config.h file:
 *   (1) copy this file to "user_config_override.h" (It will be ignored by Git)
 *   (2) define your own settings below
 *
 ******************************************************************************************************
 * ATTENTION:
 *   - Changes to SECTION1 PARAMETER defines will only override flash settings if you change define CFG_HOLDER.
 *   - Expect compiler warnings when no ifdef/undef/endif sequence is used.
 *   - You still need to update my_user_config.h for major define USE_MQTT_TLS.
 *   - All parameters can be persistent changed online using commands via MQTT, WebConsole or Serial.
\*****************************************************************************************************/

/*
Examples :

// -- Master parameter control --------------------
#undef  CFG_HOLDER
#define CFG_HOLDER        4617                   // [Reset 1] Change this value to load SECTION1 configuration parameters to flash

// -- Setup your own Wifi settings  ---------------
#undef  STA_SSID1
#define STA_SSID1         "YourSSID"             // [Ssid1] Wifi SSID

#undef  STA_PASS1
#define STA_PASS1         "YourWifiPassword"     // [Password1] Wifi password

// -- Setup your own MQTT settings  ---------------
#undef  MQTT_HOST
#define MQTT_HOST         "your-mqtt-server.com" // [MqttHost]

#undef  MQTT_PORT
#define MQTT_PORT         1883                   // [MqttPort] MQTT port (10123 on CloudMQTT)

#undef  MQTT_USER
#define MQTT_USER         "YourMqttUser"         // [MqttUser] Optional user

#undef  MQTT_PASS
#define MQTT_PASS         "YourMqttPass"         // [MqttPassword] Optional password

// You might even pass some parameters from the command line ----------------------------
// Ie:  export PLATFORMIO_BUILD_FLAGS='-DUSE_CONFIG_OVERRIDE -DMY_IP="192.168.1.99" -DMY_GW="192.168.1.1" -DMY_DNS="192.168.1.1"'

#ifdef MY_IP
#undef  WIFI_IP_ADDRESS
#define WIFI_IP_ADDRESS     MY_IP                // Set to 0.0.0.0 for using DHCP or enter a static IP address
#endif

#ifdef MY_GW
#undef  WIFI_GATEWAY
#define WIFI_GATEWAY        MY_GW                // if not using DHCP set Gateway IP address
#endif

#ifdef MY_DNS
#undef  WIFI_DNS
#define WIFI_DNS            MY_DNS               // If not using DHCP set DNS IP address (might be equal to WIFI_GATEWAY)
#endif

// !!! Remember that your changes GOES AT THE BOTTOM OF THIS FILE right before the last #endif !!! 
*/

// undefining stuff to make more room

/* EXAMPLE
#ifdef USE_UNCOOL_STUFF
#undef USE_UNCOOL_STUFF
#endif
*/

// defining new, cooler stuff

// Add support for DS18x20 sensors with id sort, single scan and read retry (+2k6 code)
#ifndef USE_DS18x20
#define USE_DS18x20
#endif
#ifndef DS18X20_PULL_UP
#define DS18X20_PULL_UP
#endif

// I2C using library wire (+10k code, 0k2 mem, 124 iram)
#ifndef USE_I2C
#define USE_I2C
#endif

//[I2cDriver11] Enable BH1750 sensor (I2C address 0x23 or 0x5C) (+0k5 code)
#ifndef USE_BH1750      
#define USE_BH1750
#endif

// [I2cDriver17] Enable Xadow and Grove Mutichannel Gas sensor using library Multichannel_Gas_Sensor (+10k code)
#ifndef USE_MGS         
#define USE_MGS
#endif

// [I2cDriver2] Enable PCF8574 I/O Expander (I2C addresses 0x20 - 0x26 and 0x39 - 0x3F) (+1k9 code)
#ifndef USE_PCF8574     
#define USE_PCF8574
#endif
#ifndef USE_PCF8574_SENSOR
#define USE_PCF8574_SENSOR
#endif
#ifndef USE_PCF8574_DISPLAYINPUT
#define USE_PCF8574_DISPLAYINPUT
#endif

// Add I2C Display Support (+2k code)
#ifndef USE_DISPLAY
#define USE_DISPLAY
#endif

// Add support for DHT11, AM2301 (DHT21, DHT22, AM2302, AM2321) and SI7021 Temperature and Humidity sensor (1k6 code)
#ifndef USE_DHT
#define USE_DHT
#endif

// Send IR remote commands using library IRremoteESP8266 and ArduinoJson (+4k3 code, 0k3 mem, 48 iram)
#ifndef USE_IR_REMOTE
#define USE_IR_REMOTE
#endif
#ifdef USE_IR_RECEIVE
#undef USE_IR_RECEIVE
#endif

// Add support for Thermostat
#ifndef USE_THERMOSTAT
#define USE_THERMOSTAT
#endif
#define THERMOSTAT_SENSOR_NAME "DHT22"

// Add support for RF transceiver using library RcSwitch (+2k7 code, 460 iram)
#ifndef USE_RC_SWITCH
#define USE_RC_SWITCH
#endif


#endif  // _USER_CONFIG_OVERRIDE_H_

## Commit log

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2021-01-17 Create DC-DC converter in KiCad as seperate project for testing
    [DC-DC-only.kicad_pcb, DC-DC-only.sch]
2021-01-18 Add new 3d footprint for SLO0630H
    [DC-DC-only.kicad_pcb, DC-DC-only.sch]
2021-01-18 Create v0.1 of DC-DC-only PCB and export gerber files
    [DC-DC-only-B_Cu.gbl, DC-DC-only-B_Mask.gbs, DC-DC-only-B_Paste.gbp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]
2021-01-18 Remove single gerbers and add timestamp to gerber zip
    [DC-DC-only-B_Cu.gbl, DC-DC-only-B_Mask.gbs, DC-DC-only-B_Paste.gbp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]
2021-01-18 Collect fabrication outputs for today
    [BOM_DC-DC-only_202101081950.csv, POS_DC-DC-only_202101181950.csv]
2021-01-18 Fix production files before ordering
    [POS_DC-DC-only_202101181950.csv]
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2021-01-30 Add DC-DC to schematic
    [ESP-Hiro.sch]
2021-01-30 Add 3.3 V LDO to schematic
    [ESP-Hiro.sch]
2021-01-30 Paste more reusable blocks from old ESP-Hiro version into new schematic
    [ESP-Hiro.sch, Import.sch]
2021-01-30 dump parts onto PCB
    [ESP-Hiro.kicad_pcb, ESP-Hiro.sch]
2021-01-30 General work on schematic
    [ESP-Hiro.sch]
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2021-01-31 Fix schematic libraries
    [ESP-Hiro.kicad_pcb, ESP-Hiro.sch]
2021-01-31 Remove rescue lib references
    [ESP-Hiro.sch]
2021-01-31 Add USB interface to schematic
    [ESP-Hiro.sch]
2021-01-31 Dump all new components to PCB
    [ESP-Hiro.kicad_pcb, ESP-Hiro.sch]
2021-01-31 configure CP2102 as only USB powered
    [ESP-Hiro.sch]
2021-01-31 Add CP2102 schematic and shift stuff in schematic
    [ESP-Hiro.kicad_pcb, ESP-Hiro.sch]
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2021-02-01 Switch to different USB-C terminal, add some 3d Files, create some better footprints
    [ESP-Hiro.kicad_pcb, ESP-Hiro.sch]
2021-02-01 Start the new test PCB for real
    [USB-CP2102-only.kicad_pcb, USB-CP2102-only.sch]
2021-02-02 Wire up initial version of PCB
    [USB-CP2102-only.kicad_pcb, USB-CP2102-only.sch]
2021-02-03 Update USB board to KiCAD 5.99
    [USB-CP2102-only.kicad_pcb, USB-CP2102-only.kicad_sch]
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2021-02-03 Create initial gerbers and BOM for USB testo
    [USB-CP2102-only-B_Cu.gbr, USB-CP2102-only-B_Mask.gbr, USB-CP2102-only-B_Paste.gbr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]
2021-02-03 Actually create pos file and zip gerbers for USB testo
    [USB-CP2102-only-B_Cu.gbr, USB-CP2102-only-B_Mask.gbr, USB-CP2102-only-B_Paste.gbr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]
2021-02-03 fix alignment in pos file for USB testo
    [USB-CP2102-only-top-pos.csv]
2021-02-06 further update USB-CP2102-only to Kicad 5.99
    [ESP-Hiro.kicad_pcb, ESP-Hiro.kicad_sch, USB-CP2102-only.kicad_pcb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]
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2021-02-06 Remove rescue lib links in ESP-Hiro PCB
    [ESP-Hiro.kicad_sch, ESP-Hiro.sch, Import.sch]
2021-02-06 Totally remove rescue lib from ESP-Hiro PCB
    [ESP-Hiro.kicad_pcb]
2021-02-06 Port DC-DC-only to KiCAD 5.99, remove rescue libs, order CP2102 USB gerbers
    [DC-DC-only.kicad_pcb, DC-DC-only.kicad_sch, DC-DC-only.sch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]
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2021-02-06 Add a bunch of logos, symbols and holes
    [ESP-Hiro.kicad_pcb, ESP-Hiro.kicad_sch]
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2021-02-07 Add license logo to PCB
    [ESP-Hiro.kicad_pcb, ESP-Hiro.kicad_sch]
2021-02-07 Add plugs to BOM but not PCB, add demo footprint for 2.54 headers
    [ESP-Hiro.kicad_pcb, ESP-Hiro.kicad_sch]
2021-02-07 exclude jumpers from BOM
    [ESP-Hiro.kicad_sch]
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2021-02-07 Add IR blaster to schematic PCB and documentation
    [ESP-Hiro.kicad_pcb, ESP-Hiro.kicad_sch]
2021-02-07 Fix 3d library stuff and edit some logo properties
    [ESP-Hiro.kicad_pcb]
2021-02-07 Reduce number of individual components, specifically headers. Add 433MHz stuff.
    [ESP-Hiro.kicad_pcb, ESP-Hiro.kicad_sch]
2021-02-15 Change IR LED source to 5 V and update resistors accordingly
    [ESP-Hiro.kicad_sch]
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2021-02-15 Add DC inputs - create BOM for testing
    [ESP-Hiro.csv, ESP-Hiro.kicad_pcb, ESP-Hiro.kicad_sch]
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2021-02-16 Put ADC and IR on one 4-pin header instead of two seperate ones
    [ESP-Hiro.kicad_sch]
2021-02-16 Add and map new footprint for 4 pin sockets
    [ESP-Hiro.kicad_pcb, ESP-Hiro.kicad_sch]
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2021-02-16 Fix symbol naming and export initial gerbers for price targeting
    [ESP-Hiro.csv, ESP-Hiro.kicad_pcb, ESP-Hiro.kicad_sch]
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2021-03-03 Add icon for shottky diode - need to reannotate jacks
    [ESP-Hiro.kicad_sch]
2021-03-06 Add lessons learned to CP2102 + USB board
    [BOM_DC-DC-only_202101081950.csv, POS_DC-DC-only_202101181950.csv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]
2021-03-06 Reset annotations
    [ESP-Hiro.kicad_sch]
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2021-03-07 Swap some pins during routing
    [ESP-Hiro.kicad_pcb, ESP-Hiro.kicad_sch]
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2021-03-07 Change jack footprints - run DRC without silkscreen - no errors
    [ESP-Hiro.kicad_pcb]
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2021-03-07 Minor optimizations - no DRC errors or real warnings
    [ESP-Hiro.kicad_pcb]
2021-03-07 Found overlapping courtyards - NOW no DRC errors
    [ESP-Hiro.kicad_pcb]
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2021-03-09 FIRST AFTER ORDER - Update mechanical and ESP footprints midpoints for better placemaps in future
    [ESP-Hiro.kicad_pcb]
2021-03-09 Improve silkscreen around DC input and create new WRL files
    [ESP-Hiro.kicad_pcb]
2021-03-09 More minor improvements of footprints - run DRC - generate STP and WRL
    [ESP-Hiro.kicad_pcb]
2021-03-09 Try swapping ESP 3d to stp for export
    [ESP-Hiro.kicad_pcb]
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2021-04-11 Update to newer version of KiCAD 5.99 nightly
    [ESP-Hiro.kicad_pcb, ESP-Hiro.kicad_sch]
2021-04-11 Add shottky diode between DC-DC converter and 5 V rail again
    [ESP-Hiro.kicad_pcb, ESP-Hiro.kicad_sch]
2021-04-11 Rework Schematic and PCB - not finished yet:
    - Remove uneffective 1uF caps from PWM outputs
    - Add 100uF Low ESR cap to PWM output
    - Fix PCF8574APWR footprint
    - Change some testpoints
    - Minor visual improvements to Silkscreen
    [ESP-Hiro.kicad_pcb, ESP-Hiro.kicad_sch]
2021-04-11 Finish reworking board and schematic for v1.0
    [ESP-Hiro.kicad_pcb]
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2021-04-12 Update DC-DC voltage setting resistor divider to raise voltage for new diode
    [ESP-Hiro.kicad_pcb, ESP-Hiro.kicad_sch]
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2021-04-12 Create fabrication files and order board v1.0 after minor modifications
    [ESP-Hiro.kicad_pcb, ESP-Hiro.kicad_sch, ESP-Hiro_V1_0_BOM.csv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]
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2021-04-13 Add 5.08mm plugs to 3d view and export new renders
    [ESP-Hiro.kicad_pcb]
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2021-04-15 Create FreeCAD project and add colorized PCB to it
    [ESP-Hiro.FCStd]
2021-04-16 Fix left screw header distance
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2021-04-17 Fix width of 5.08 terminals for 3d printing
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2021-04-19 Fix folders
    [BOM.csv, BOM_DC-DC-only_202101081950.csv, DC-DC-only.kicad_pcb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]
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2021-05-11 [V1.0.1] Update Binary-6 Logo and add UNTESTED gerbers
    [ESP-Hiro-B_Cu.gbl, ESP-Hiro-B_Mask.gbs, ESP-Hiro-B_Paste.gbp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]
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2021-05-17 Add untested v1.0.1 gerber files to be ordered as soon as parts are available
    [ESP-Hiro_V1_0_1_BOM.csv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]
2021-05-24 Swap 3vV3 LDO to available part and order V1.0.1
    [ESP-Hiro.kicad_pcb, ESP-Hiro.kicad_sch, ESP-Hiro_V1_0_1_BOM_Hand.csv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]
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

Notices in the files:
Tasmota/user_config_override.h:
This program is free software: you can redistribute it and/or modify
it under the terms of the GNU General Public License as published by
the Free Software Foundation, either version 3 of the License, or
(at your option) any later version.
